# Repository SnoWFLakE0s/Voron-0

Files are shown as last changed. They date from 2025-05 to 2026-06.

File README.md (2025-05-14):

# Todo

- Machine all motion components:
  - X/Y Joints
  - Redesigned top drive frames
  - Redesigned drive spacer blocks
  - X carriage
- Design 1515 frame stiffening joint pieces (corner brackets, or possible other solution)
- Insulated & soundproofed panel material sourcing and design
- Add chamber temp & humidity sensor
- [Add E-stop switch](https://www.aliexpress.com/item/1005003097509121.html)
- Add chamber camera
- Possibly redesign for flip-out electronics cabinet/control panel (relocate display, possibly use larger screen)
- Debate [nevermore filter](https://www.aliexpress.com/item/1005005621338360.html)

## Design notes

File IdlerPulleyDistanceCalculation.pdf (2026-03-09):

# Idler & Pulley Meshing Computation in CoreXY Systems

Joshua Eah

March 2026

## 1 Introduction

To ensure perfect kinematics in a CoreXY system, the pitch line of the timing belt must remain perfectly parallel to the axis of motion. Here we compute the ideal X-axis offset for a motion

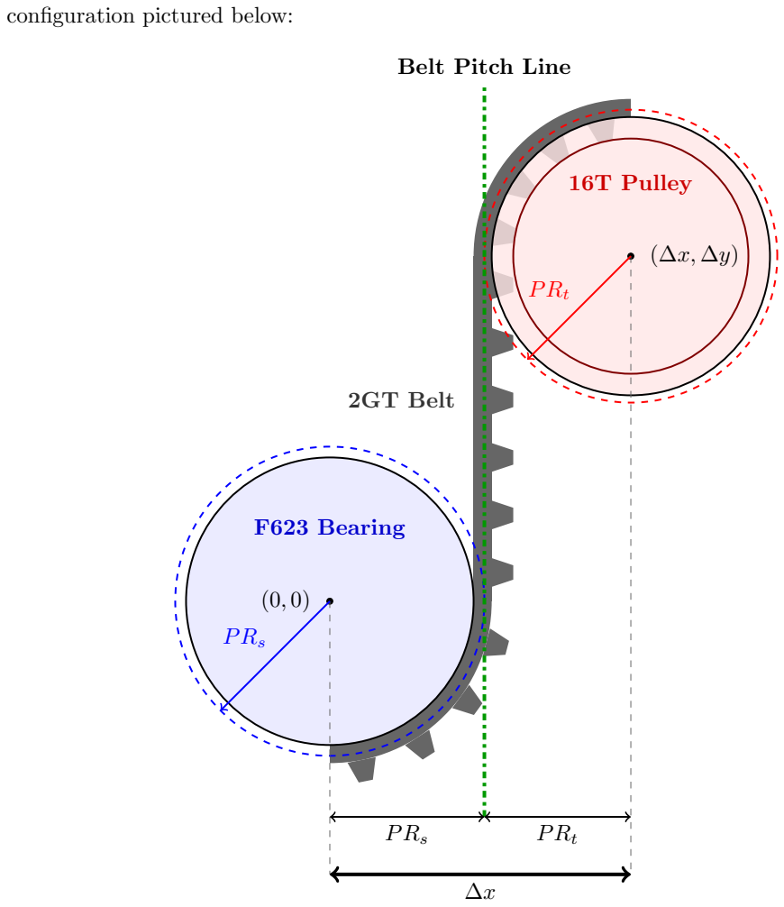
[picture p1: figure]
configuration pictured below:; F623 Bearing; 16T Pulley; Belt Pitch Line; 2GT Belt

1

1.1 2GT Belt Specifications

- Total Thickness (H): 1.38 mm
- Tooth Height (h): 0.75 mm
- Back/Web Thickness (i): 0.63 mm
- Pitch Line Differential (P LD): 0.254 mm

### 1.2 Hardware Specifications

- F623 Bearing Outer Diameter: 10.000 mm
- 16T 2GT Pulley Pitch: 2.000 mm
- 16T 2GT Pulley Tooth Count (N): 16

## 2 Pitch Radius Calculations

### 2.1 F623 Smooth Idler (P Rs)

When the flat back of the belt rides against a smooth idler, the pitch line is offset outwards. We first calculate the distance from the flat back to the pitch line (tpitch):

tpitch = i − P LD = 0.63 mm − 0.254 mm = 0.376 mm | (1)

Adding this to the radius of the F623 bearing gives the smooth pitch radius:

P Rs =

10.000
2
+ 0.376 = 5.376 mm | (2)

2.2 16T Toothed Pulley (P Rt)

For the toothed pulley, the pitch radius is derived strictly from the tooth count and pitch:

P Rt =

N · Pitch
2π

=

16 · 2
2π
≈ 5.093 mm | (3)

## 3 Ideal X-Offset

Assuming the belt must run perfectly parallel to the Y-axis between the two components, the ideal X-offset is the sum of their respective pitch radii:

Xof f set = P Rs + P Rt = 5.376 + 5.093 = 10.469 mm | (4)

2

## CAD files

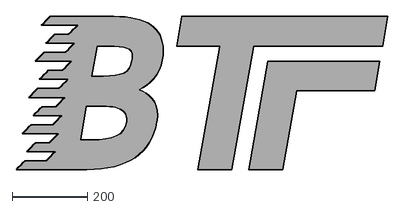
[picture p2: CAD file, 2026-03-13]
CAD/Drawings/Logo Vector.dxf
986.6 x 406.1

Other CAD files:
CAD/AB Drives/Parts/A Drive Frame Lower.dwg
CAD/X Axis/XY Joints/XY Joint Left/XY Joint Left Upper.dwg
CAD/AB Drives/Parts/B Drive Frame Lower.dwg
CAD/Idlers/Parts/A Idler.dwg
CAD/AB Drives/Parts/B Drive Frame Upper.dwg
CAD/Idlers/Parts/B Idler.dwg
CAD/AB Drives/Parts/A Drive Frame Upper.dwg
CAD/Idlers/Parts/Bearing Nut.dwg
CAD/AB Drives/A_Drive.iam
CAD/AB Drives/B_Drive.iam
CAD/AB Drives/Parts/A Drive Frame Lower.ipt
CAD/AB Drives/Parts/A Drive Frame Upper.ipt
CAD/AB Drives/Parts/B Drive Frame Lower.ipt
CAD/AB Drives/Parts/B Drive Frame Upper.ipt
CAD/AB Drives/Parts/Drive Frame Spacer.ipt
CAD/AB Drives/Parts/Nema14.ipt
CAD/Belts/Belts.iam
CAD/Belts/Parts/A Belt.ipt
CAD/Belts/Parts/B Belt.ipt
CAD/Display/Display.iam
CAD/Display/Parts/Display Diffuser.ipt
CAD/Display/Parts/Display Faceplate.ipt
CAD/Display/Parts/Display Mounts.ipt
CAD/Display/Parts/Encoder Knob.ipt
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

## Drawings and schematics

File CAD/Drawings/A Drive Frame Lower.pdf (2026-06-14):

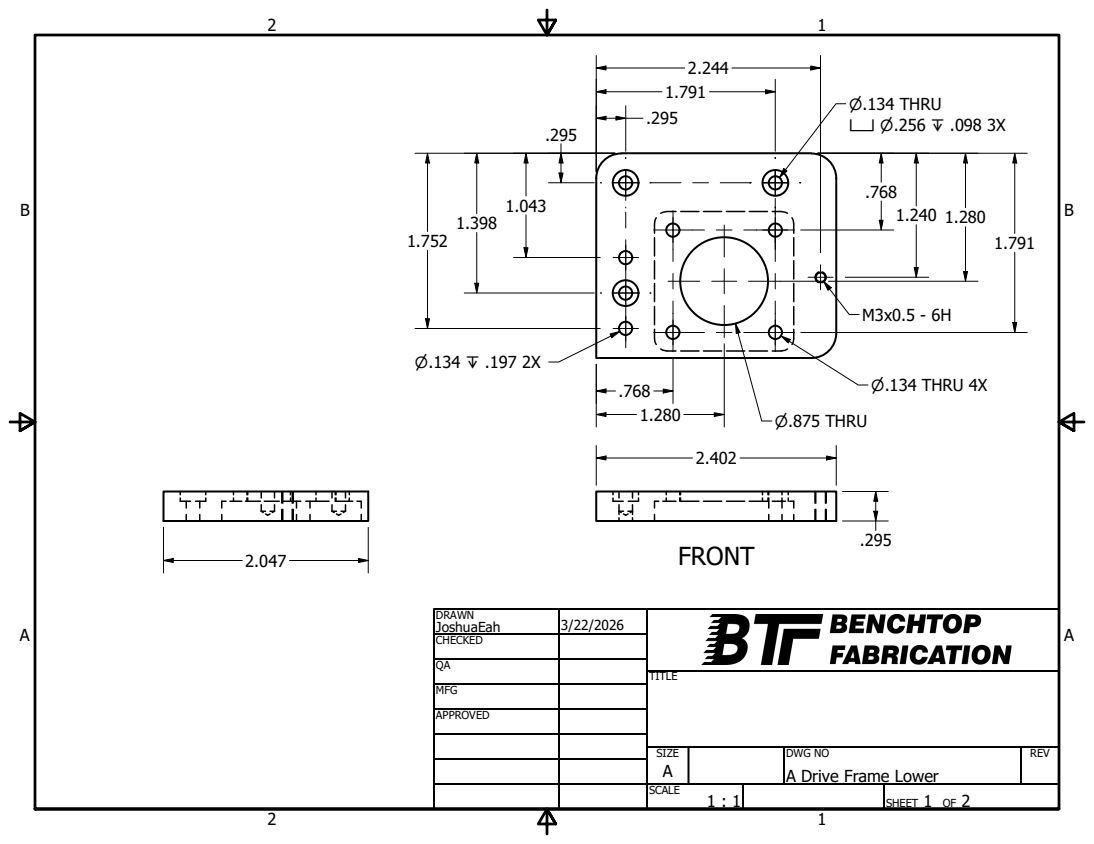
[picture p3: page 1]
⌀.134 THRU ⌴ ⌀.256 ↧ .098 3X; ⌀.134 THRU 4X; ⌀.875 THRU

DRAWN JoshuaEah | 3/22/2026

CHECKED

MFG

APPROVED

SIZE A | DWG NO A Drive Frame Lower | REV

SCALE 1 : 1 | | SHEET 1 OF 2

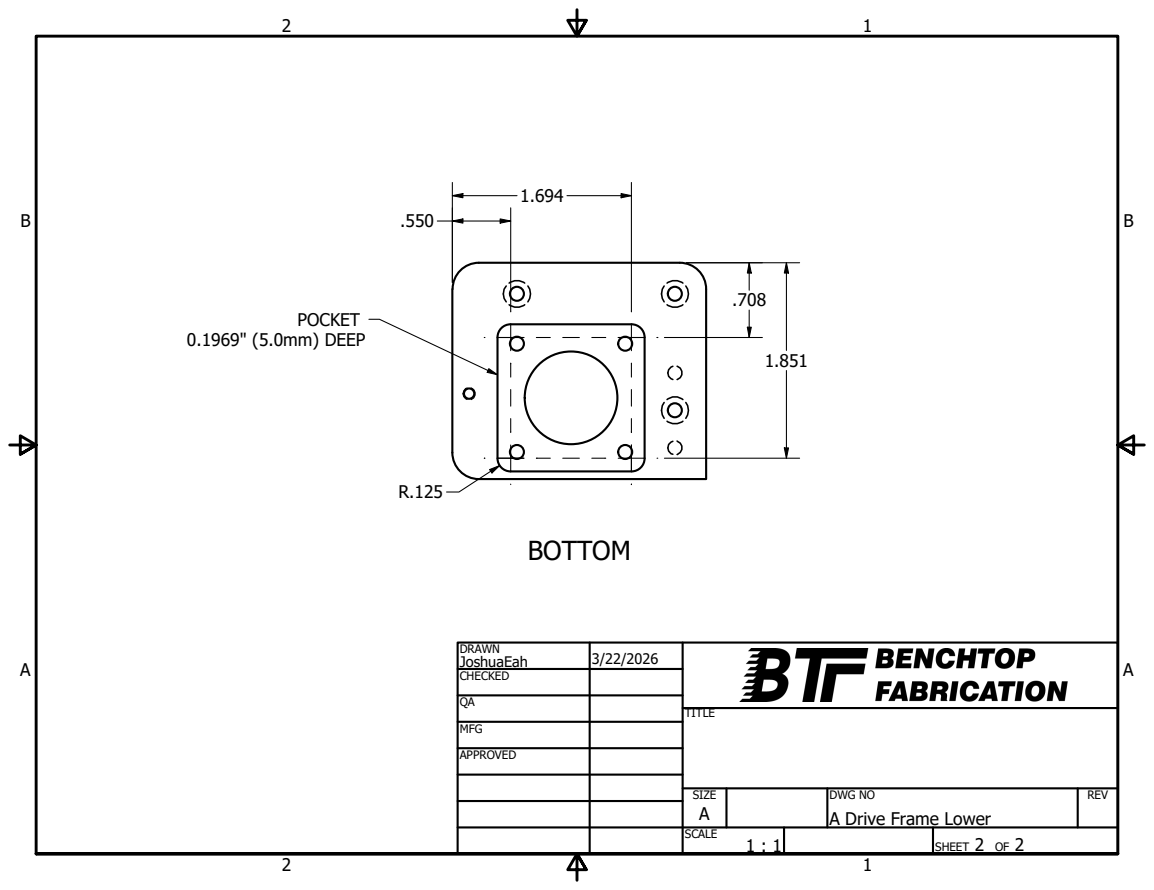
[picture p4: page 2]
0.1969" (5.0mm) DEEP

DRAWN JoshuaEah | 3/22/2026

CHECKED

MFG

APPROVED

SIZE A | DWG NO A Drive Frame Lower | REV

SCALE 1 : 1 | | SHEET 2 OF 2

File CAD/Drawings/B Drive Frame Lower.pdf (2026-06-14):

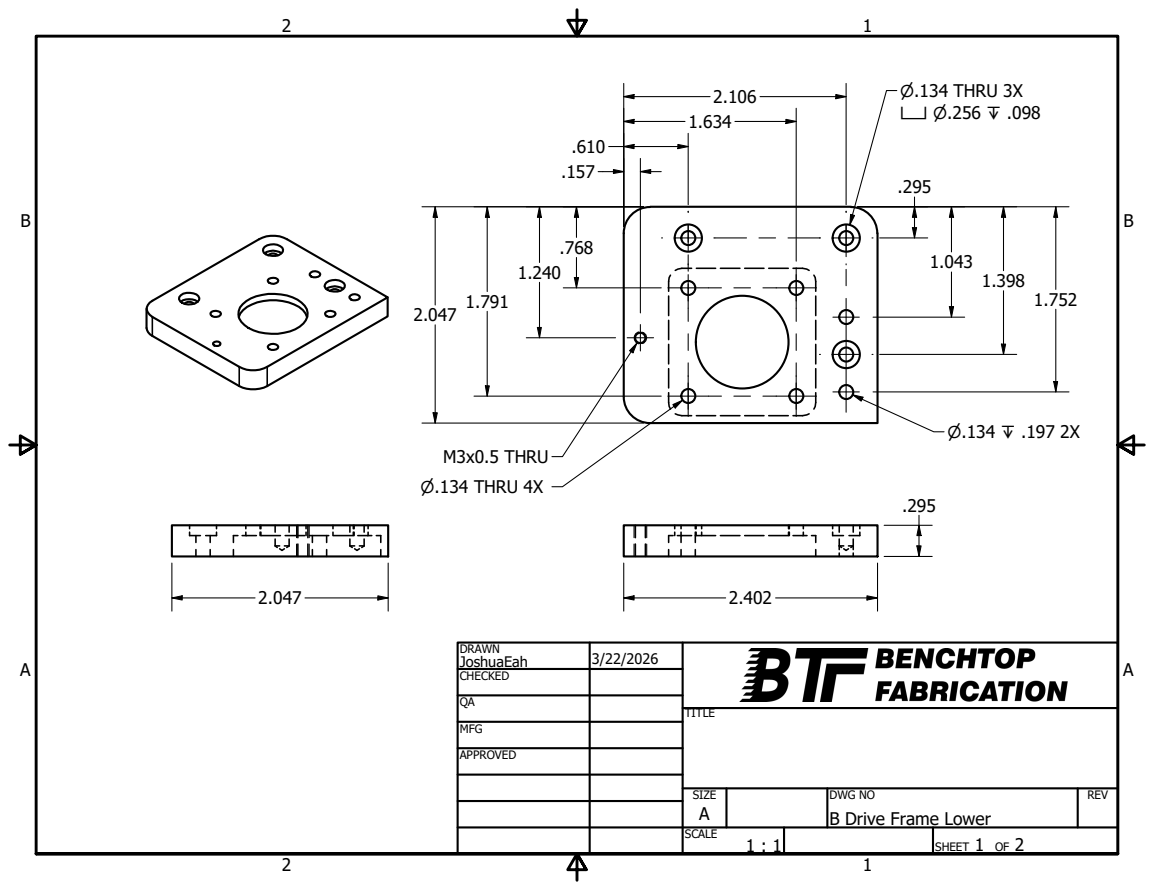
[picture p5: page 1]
M3x0.5 THRU ⌀.134 THRU 4X; ⌀.134 THRU 3X ⌴ ⌀.256 ↧ .098

DRAWN JoshuaEah | 3/22/2026

CHECKED

MFG

APPROVED

SIZE A | DWG NO B Drive Frame Lower | REV

SCALE 1 : 1 | | SHEET 1 OF 2

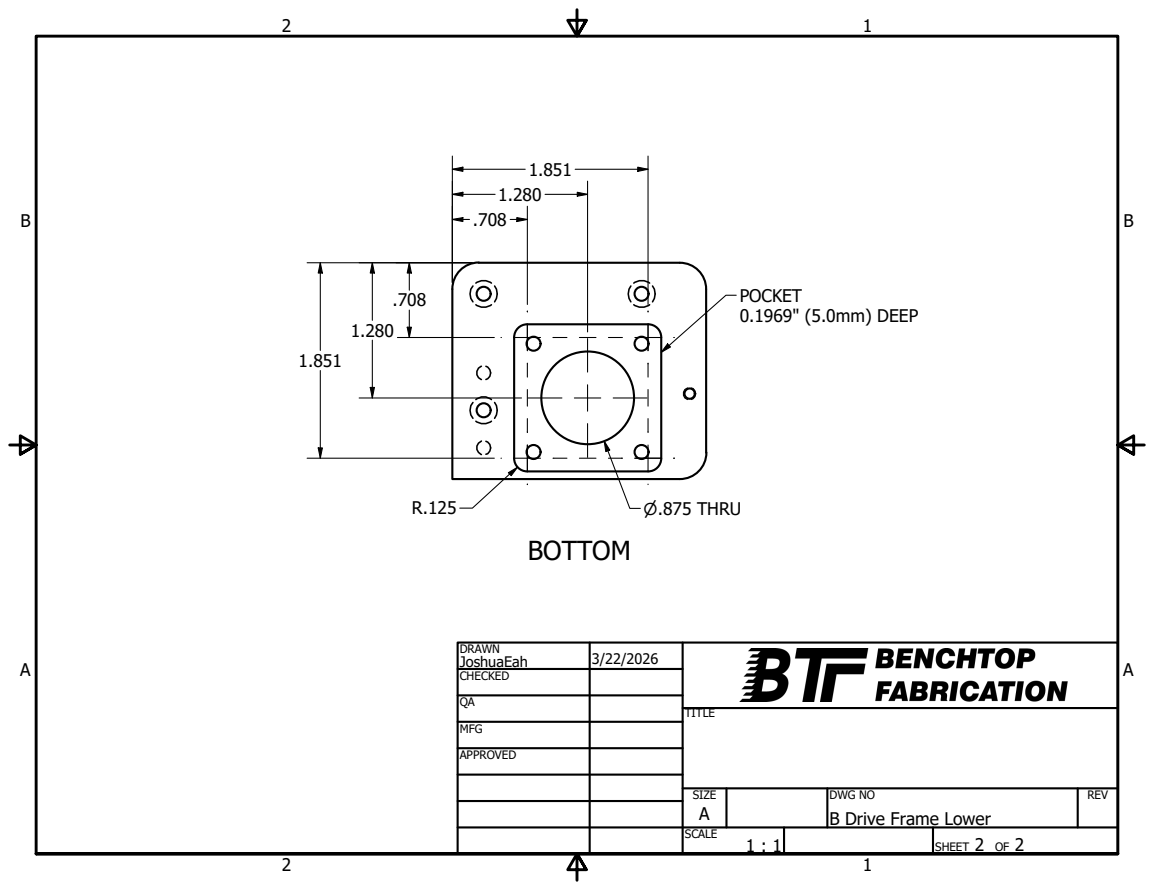
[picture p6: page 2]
0.1969" (5.0mm) DEEP; ⌀.875 THRU

DRAWN JoshuaEah | 3/22/2026

CHECKED

MFG

APPROVED

SIZE A | DWG NO B Drive Frame Lower | REV

SCALE 1 : 1 | | SHEET 2 OF 2

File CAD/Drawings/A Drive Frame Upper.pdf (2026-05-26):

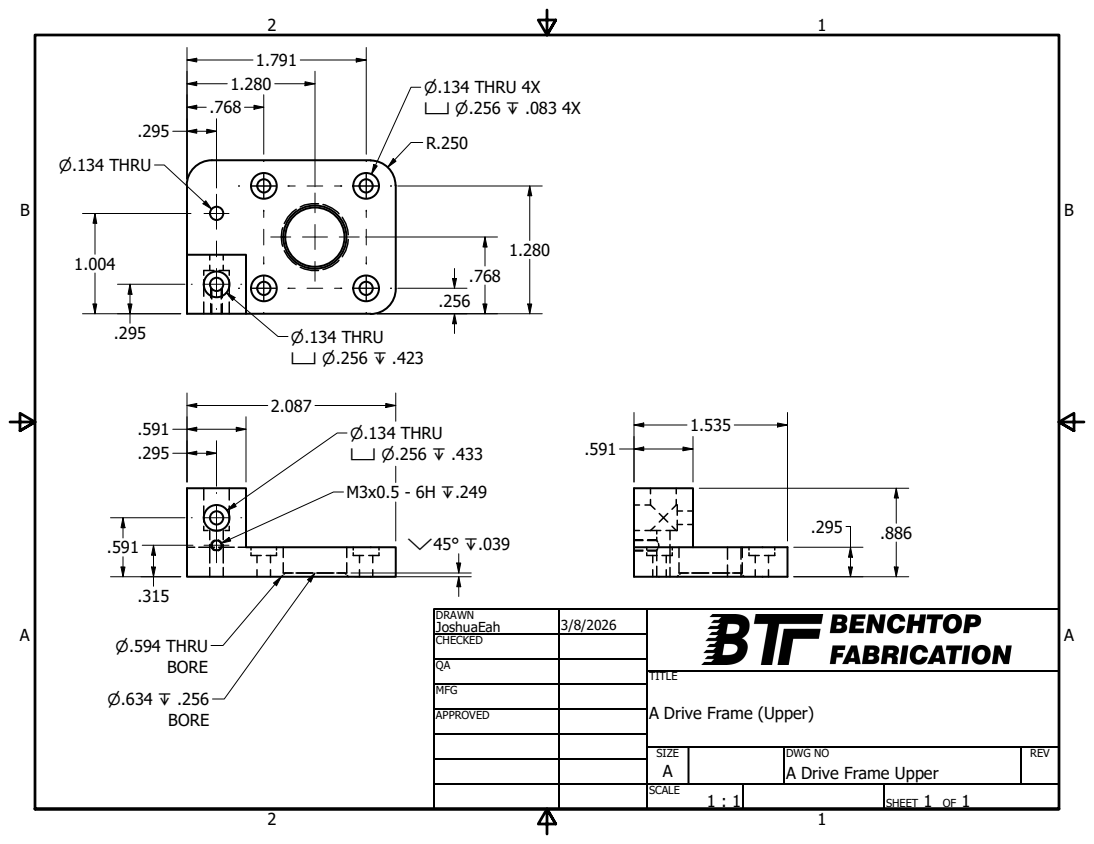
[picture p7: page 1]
⌀.134 THRU ⌴ ⌀.256 ↧ .433; ⌀.134 THRU 4X ⌴ ⌀.256 ↧ .083 4X; ⌀.134 THRU; ⌀.134 THRU ⌴ ⌀.256 ↧ .423; ⌀.594 THRU

DRAWN JoshuaEah | 3/8/2026

CHECKED

MFG

APPROVED

A Drive Frame (Upper)

SIZE A | DWG NO A Drive Frame Upper | REV

SCALE 1 : 1 | | SHEET 1 OF 1

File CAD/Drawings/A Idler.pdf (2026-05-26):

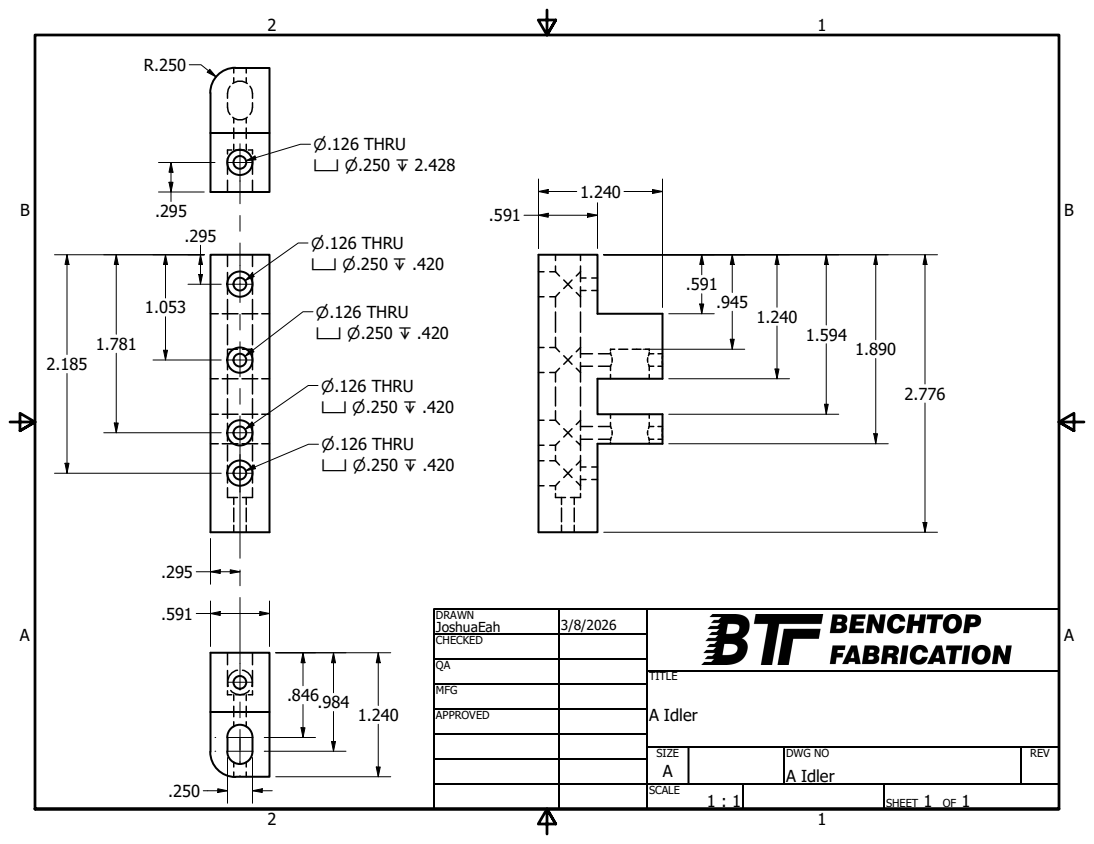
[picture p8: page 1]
A Idler; ⌀.126 THRU ⌴ ⌀.250 ↧ .420; ⌀.126 THRU ⌴ ⌀.250 ↧ 2.428

DRAWN JoshuaEah | 3/8/2026

CHECKED

MFG

APPROVED

SIZE A | DWG NO A Idler | REV

SCALE 1 : 1 | | SHEET 1 OF 1

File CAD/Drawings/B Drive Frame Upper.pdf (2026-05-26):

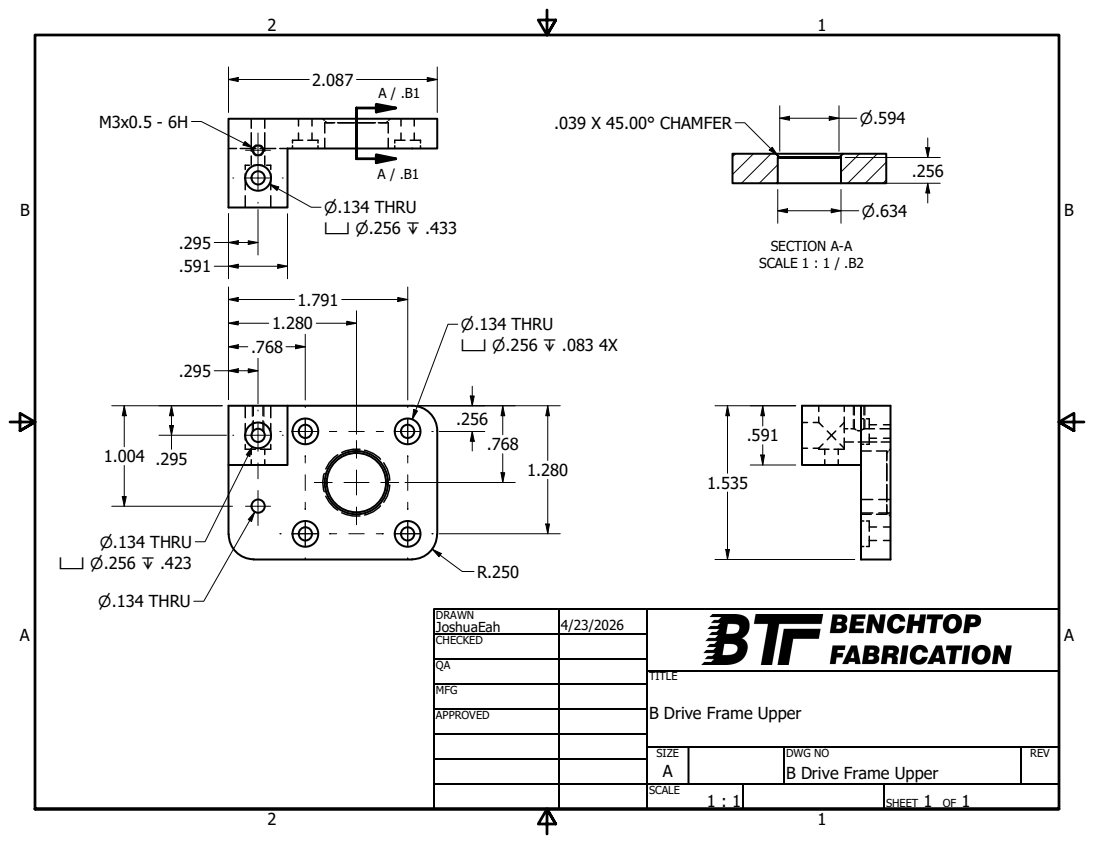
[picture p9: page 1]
SECTION A-A SCALE 1 : 1 / .B2; ⌀.134 THRU ⌴ ⌀.256 ↧ .083 4X; ⌀.134 THRU ⌴ ⌀.256 ↧ .423; ⌀.134 THRU; ⌀.134 THRU ⌴ ⌀.256 ↧ .433; ⌀.594 .039 X 45.00° CHAMFER

DRAWN JoshuaEah | 4/23/2026

CHECKED

MFG

APPROVED

B Drive Frame Upper

SIZE A | DWG NO B Drive Frame Upper | REV

SCALE 1 : 1 | | SHEET 1 OF 1

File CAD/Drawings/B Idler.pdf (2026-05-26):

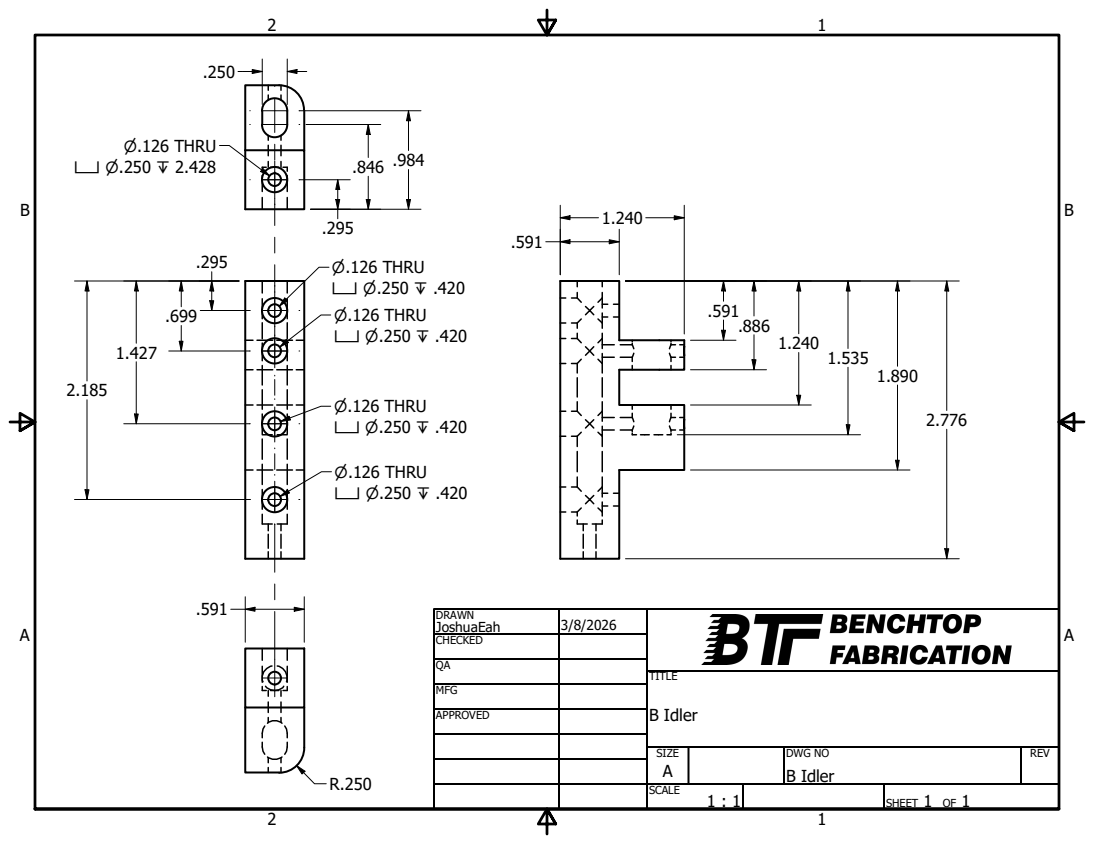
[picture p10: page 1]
B Idler; ⌀.126 THRU ⌴ ⌀.250 ↧ .420; ⌀.126 THRU ⌴ ⌀.250 ↧ 2.428

DRAWN JoshuaEah | 3/8/2026

CHECKED

MFG

APPROVED

SIZE A | DWG NO B Idler | REV

SCALE 1 : 1 | | SHEET 1 OF 1

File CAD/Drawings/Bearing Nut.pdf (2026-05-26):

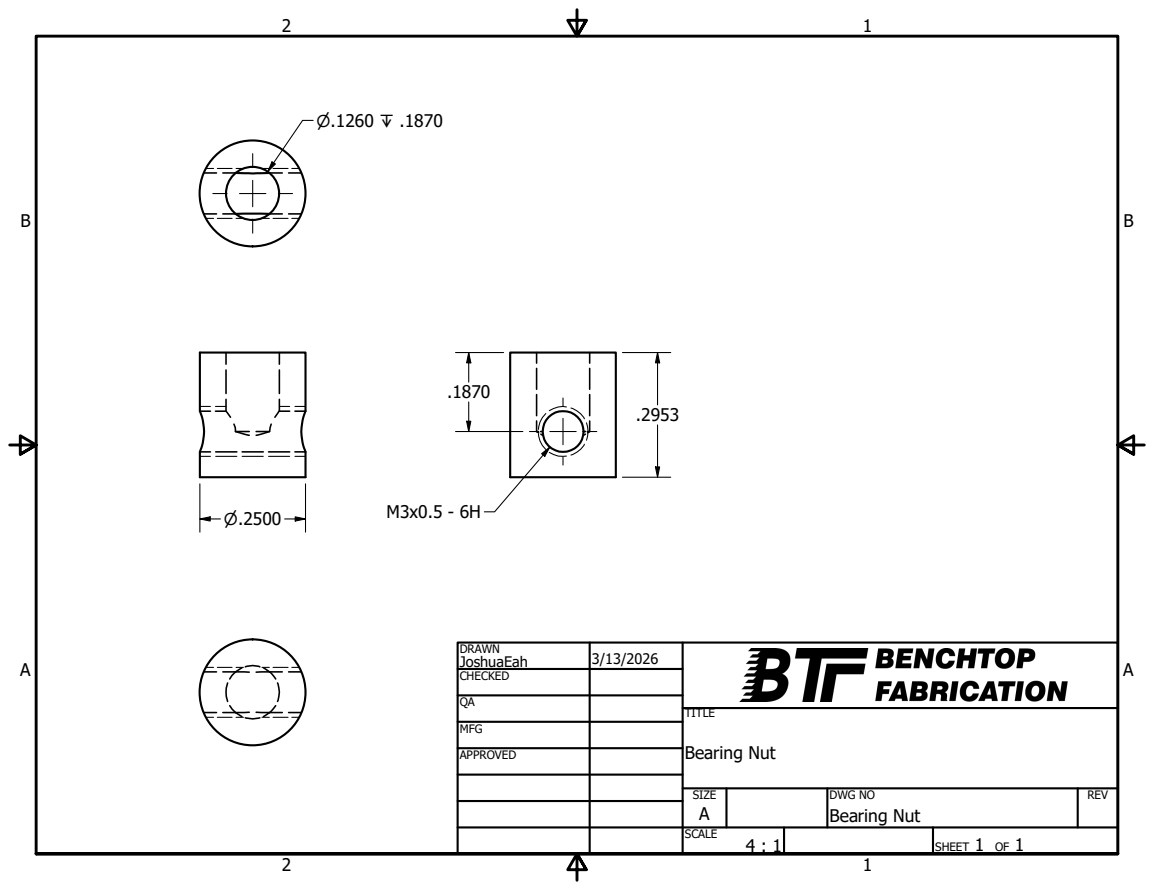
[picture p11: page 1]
Bearing Nut

DRAWN JoshuaEah | 3/13/2026

CHECKED

MFG

APPROVED

SIZE A | DWG NO Bearing Nut | REV

SCALE 4 : 1 | | SHEET 1 OF 1

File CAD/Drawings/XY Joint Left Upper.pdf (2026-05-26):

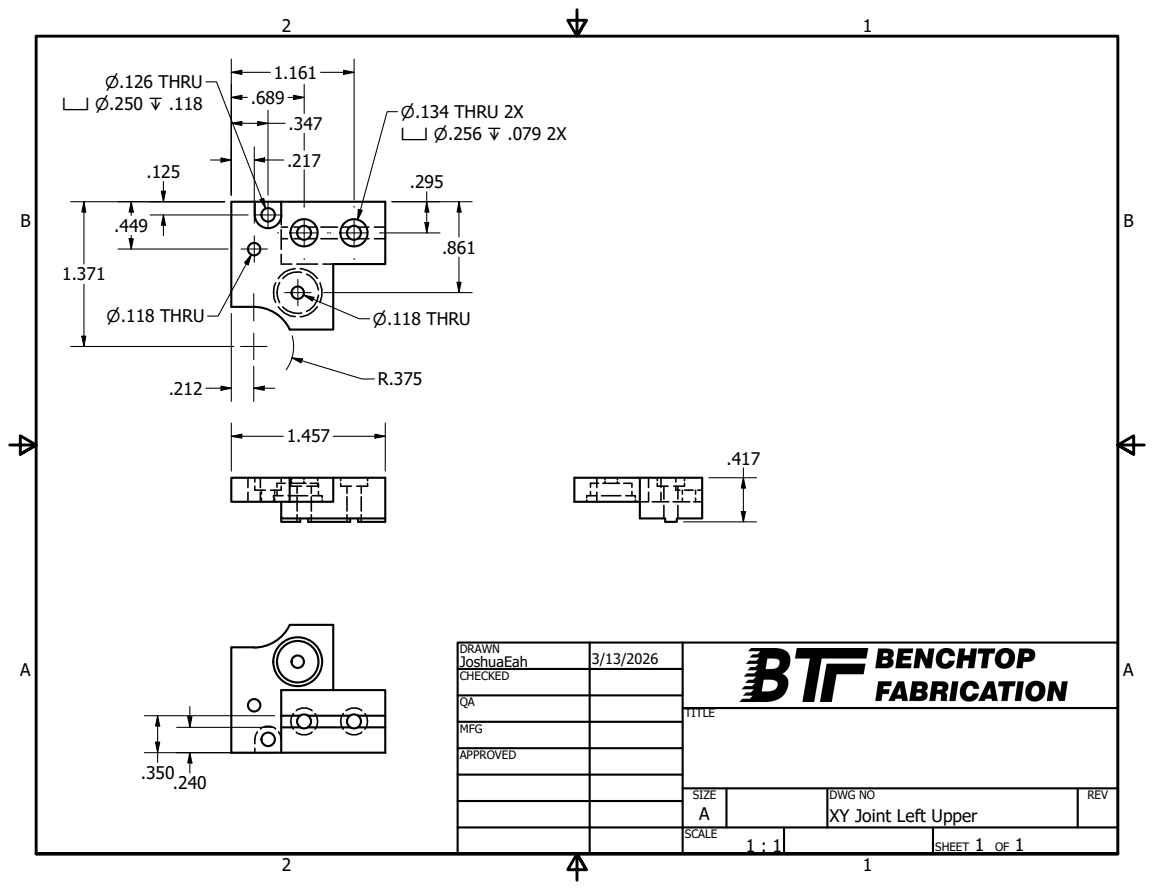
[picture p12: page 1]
⌀.134 THRU 2X ⌴ ⌀.256 ↧ .079 2X; ⌀.126 THRU ⌴ ⌀.250 ↧ .118; ⌀.118 THRU

DRAWN JoshuaEah | 3/13/2026

CHECKED

MFG

APPROVED

SIZE A | DWG NO XY Joint Left Upper | REV

SCALE 1 : 1 | | SHEET 1 OF 1

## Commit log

2025-05-25 some work
    [040-07-12 (1).ipt, 040-07-12.ipt, 100x100mm Silicone Bed Heater.0001.ipt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]
2025-06-28 basic changes
    [3x12 Pin.ipt, 6x3mm Magnet.ipt, A Idler (Tulip).ipt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]
2025-10-29 Redesigned idler-tensioners & file organization changes.
    Overhauled Tulip idler assemblies, removing legacy designs and introducing new A/B Idler assemblies and parts. Updated multiple assemblies and subassemblies to reflect these changes.
    [16T_Pulley.ipt, 6x3mm Magnet.ipt, A Drive Frame Lower (Tulip).ipt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]
2025-11-13 Final Tulip modifications
    Final "Tulip-only" seperate modification before merge.
    [A Idler (Tulip) Assembly.iam, B Idler (Tulip) Assembly.iam, Extrusions.iam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]
2025-11-13 Integrate Tulip mod components
    Fully integrated Tulip mod components into the regular V0.2 assembly, cleaned up file structure
    [040-07-12 (1).ipt, 040-07-12.ipt, 100x100mm Silicone Bed Heater.ipt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]
2025-11-15 Revised hotend models & updated materials
    [Bearing Nut.ipt, Formbot Mount.ipt, Heatblock.ipt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]
2025-11-25 Add Nevermore V6 CAD
    Added new CAD files for the Nevermore V6 Micro system, including assembly and part files, as well as new electronics components such as the 5015 Fan and related parts. Also added alternate idler asse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
    [5015 Fan.iam, A Drive Frame Upper.ipt, B Idler (Alternate).ipt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]
2025-12-08 proposed experimental idler configuration
    - added alternate, cut extrusion
    - added extended idler
    [1515_200mm - D (Alternate).ipt, A Idler (Alternate).ipt, A Idler Assembly (Alternate).iam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]
2025-12-11 Remove unused idler assembly and bearing carriage files
    Updated B idler (alternate) to match A alternate config
    [B Idler (Alternate).ipt, B Idler Assembly (Alternate).iam, Bearing Carriage.ipt]
2025-12-11 Updated all assemblies to new alternate configuration
    - Fixed errors on slot for B idler (alternate)
    - Updated assemblies to properly reflect new alternate design configuration
    [B Idler (Alternate).ipt, B Idler Assembly (Alternate).iam, Voron 0.iam]
2026-02-20 Update gantry/idlers
    - Changed idler/tensioner travel to 3.5mm
    - Adjust clearance cuts on XY joints to 1mm, fillets adjusted to 3/8"
    [A Idler (Alternate).ipt, A Idler Assembly (Alternate).iam, B Idler (Alternate).ipt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]
2026-02-27 Updated idler length
    - Changed frame cut from 15mm*1.25 to 15mm*1.5
    - Updated idlers accordingly
    [1515_200mm - D (Alternate).ipt, A Idler (Alternate).ipt, A Idler Assembly (Alternate).iam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]
2026-03-01 Fixed misalignment & file organization
    - XY Joint Right was missing the correct offset for idler height
    - Changed bearing seat heights on the upper and lower joints to correct the issue
    - Renamed "alternate" extrusion to reflect current state
    [1515_177.5mm - D.ipt, Frame.iam, Voron 0.iam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]
2026-03-09 Fixed pitch line computation for idlers
    - Fixed pitch line computation for idlers
    - Renamed idler parts
    [A Idler Assembly (Alternate).iam, A Idler Assembly.iam, A Idler Reinforced.ipt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]
2026-03-09 Added writeup on idler/pulley meshing
2026-03-12 Added B idler drawing, updated views
    [B Drive Frame Upper.ipt, B Idler.dwg]
2026-03-12 Add idler PDFs and update idler DWG files
    Add new PDF drawings for A Idler and B Idler under CAD/Drawings, and apply revisions to the corresponding DWG part files in CAD/Idlers/Parts (A Idler.dwg, B Idler.dwg).
    [A Idler.dwg, B Idler.dwg]
2026-03-13 Add DXF logo and update/add drawings
    [A Idler.dwg, Bearing Nut.dwg, Logo Vector.dwg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]
2026-03-23 New drawings
    [A Drive Frame Lower.dwg, B Idler.dwg]
2026-03-26 Updated bearing nut model to as-manufactured specification
    [Bearing Nut.ipt]
2026-03-29 Updated drawings with missing dims
    [A Idler Assembly.iam, A Idler.dwg, B Idler Assembly.iam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]
2026-04-06 Create A Drive Frame Upper.dwg
    [A Drive Frame Upper.dwg]
2026-04-06 Fixed title block
    [A Drive Frame Upper.dwg, A Idler.dwg, B Idler.dwg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]
2026-04-06 Create A Drive Frame Upper.pdf
2026-04-15 Update A Drive Frame Upper.dwg
    [A Drive Frame Upper.dwg]
2026-05-26 Updated drawings
    [A Drive Frame Upper.dwg, A Idler.dwg, B Drive Frame Upper.dwg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]
